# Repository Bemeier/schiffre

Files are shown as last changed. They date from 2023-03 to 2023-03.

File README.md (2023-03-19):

# SCHIFFRE

The Schiffre project is a mechanical keyboard featuring a host board and shield design, using a Flexible Flat Cable (FFC) as interconnect.
All PCBs designed with Kicad 7.0. Case designed in Fusion.

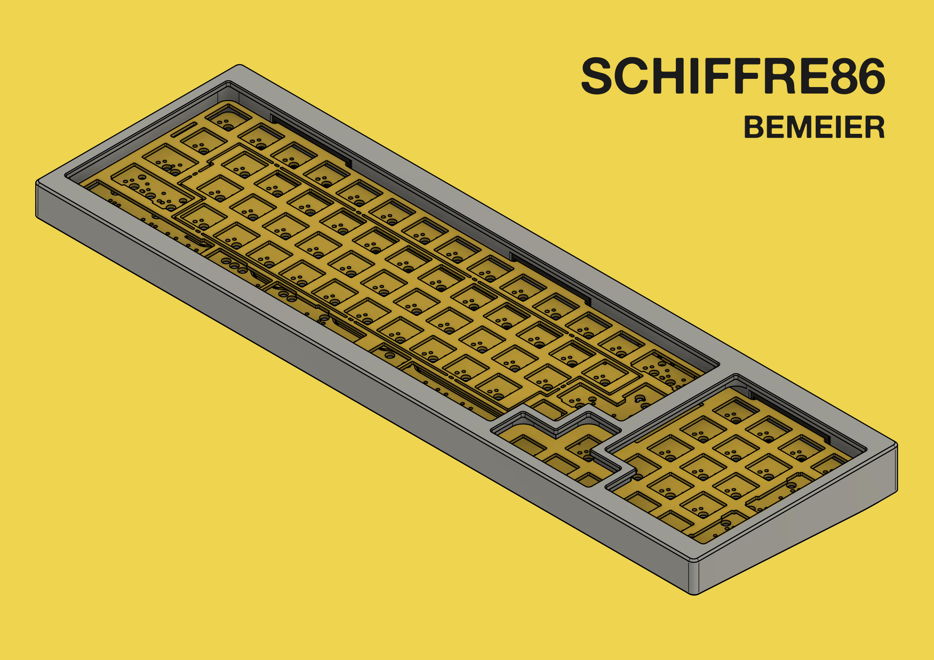
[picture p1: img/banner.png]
schiffre86 banner

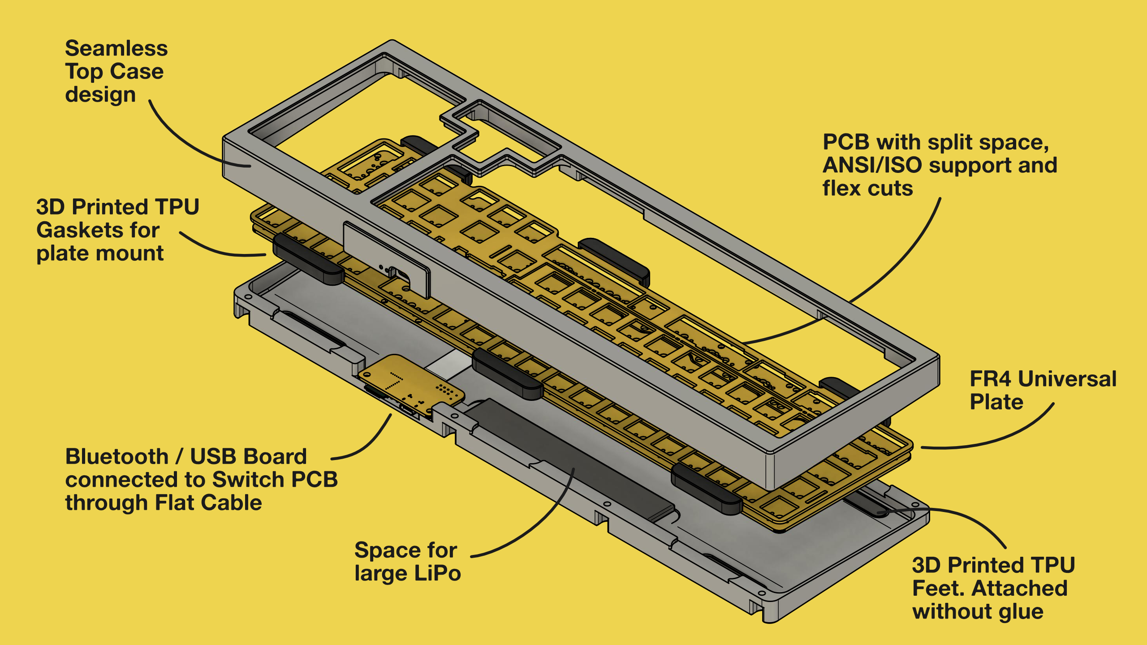
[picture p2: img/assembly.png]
schiffre86 assembly


## COMPONENTS
In this repository you will find everything to build a Schiffre 86 board.

- The host board: `schiffre_nrf`
- The shield PCB: `schiffre_86_pcb`
- The switch plate: `schiffre_86_plate`, with files for production from FR4.
- The case: `schiffre_86_case`, designed with both 3D printing and CNC machining in mind.

In addition there is a breakout board for the 30 pin FFC connector, with a RPi Pico header in `schiffre_pico`.

## BOM
See the production subfolders in the respective folders for the smd/assembly components.
Some additional components need to be ordered seperately.

**For the NRF host board (`schiffre_nrf`):**
 - One E73-2G4M08S1C bluetooth module [AliExpress](https://aliexpress.com/item/32944356249.html)
 - One 100mm reversible FFC calbe with 30 pins and .5mm pitch [AliExpress](https://aliexpress.com/item/1005002259855390.html) to connect between the host and shield pcb (`schiffre_86_pcb`).
 - A LiPo rechargable battery. There is room for a long, but narrow and thin one.
   - Thickness <= 4mm, and width <= 25mm. 
   - Make sure to only use LiPos with battery protection ICs included (usually the case).
   - 4x20x60mm 600mAh [AliExpress](https://aliexpress.com/item/1005005086965061.html)
   - 4x25x100mm 1200mAh [AliExpress](https://aliexpress.com/item/1005005067026996.html)

**For the Case (`schiffre_86_case`):**
 - M3x5.7x4.6 and M2x4x3.6 Heat-set inserts (if 3D printing the case or machining from plastics) [AliExpress](https://www.aliexpress.com/item/4001258499799.html).
 - DIN912 socket head screws: 8x M3x10mm, 4x M2x6mm [AliExpress](https://www.aliexpress.com/item/32810872544.html)
 - Plate mounting gaskets and case feet need to be 3D printed from TPU.

## FIRST BUILD
Below some pictures of the first build in progress.
PCBs from JLCPCB, case 3D printed from PETG.

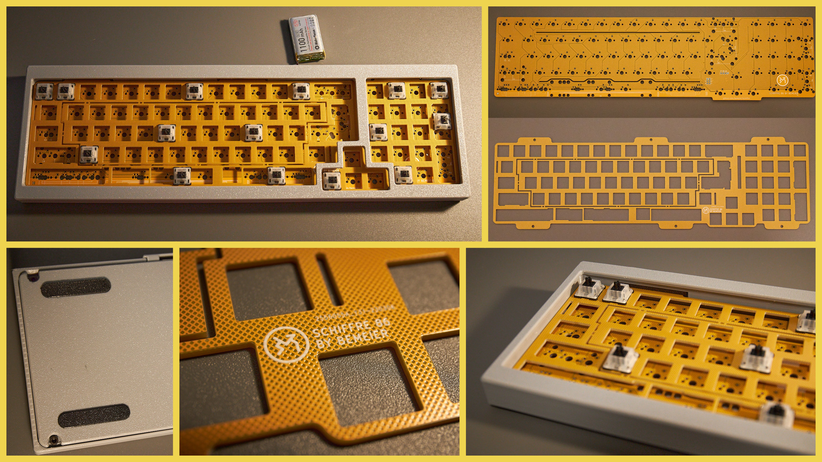
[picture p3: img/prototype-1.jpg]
pictures of prototype 1

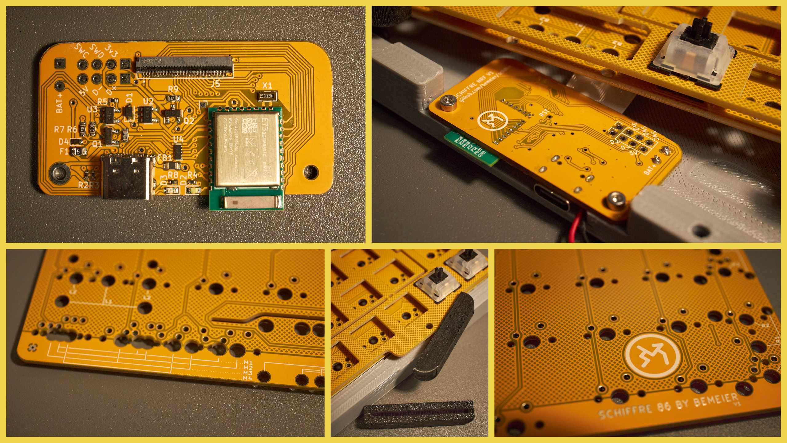
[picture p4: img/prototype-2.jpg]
pictures of prototype 2


## LAYOUTS
The schiffre86 supports both ANSI and ISO (Enter, split left shift) layouts, split backspace, and split spacebars.
See the [keyboard layout editor](http://www.keyboard-layout-editor.com/#/gists/19b67d0e8a5331e922c6eb11a3dd6522) for details.

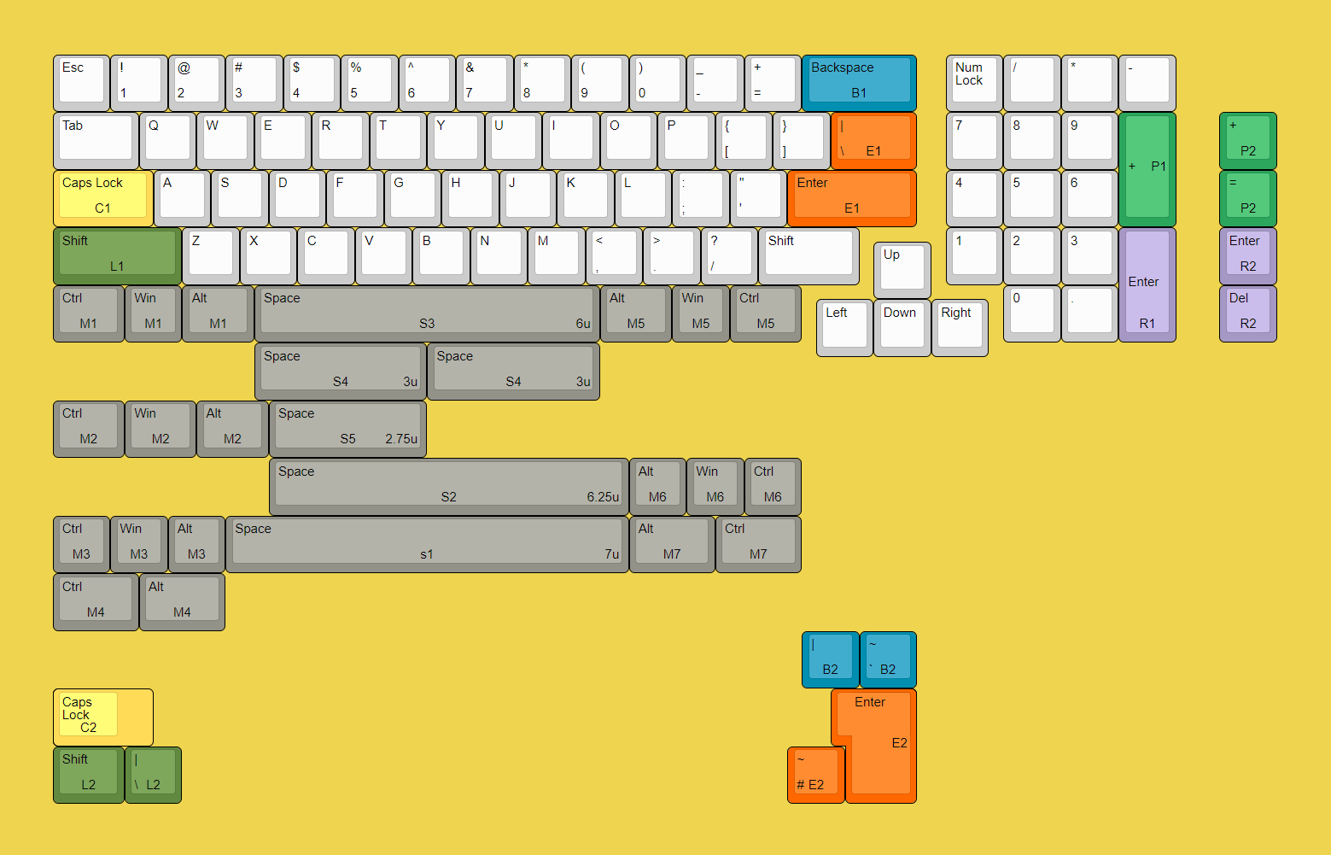
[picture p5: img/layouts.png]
schiffre86 supported layouts


## FIRMWARE
ZMK support works. See the [schiffre branch on our zmk fork](https://github.com/Bemeier/zmk/tree/schiffre). 
There is a [zmk-config template for the schiffre86](https://github.com/Bemeier/schiffre86-zmk-config) that you can clone to build your own keymap.
It comes with support for nickcoutsos' [keymap-editor](https://nickcoutsos.github.io/keymap-editor/).

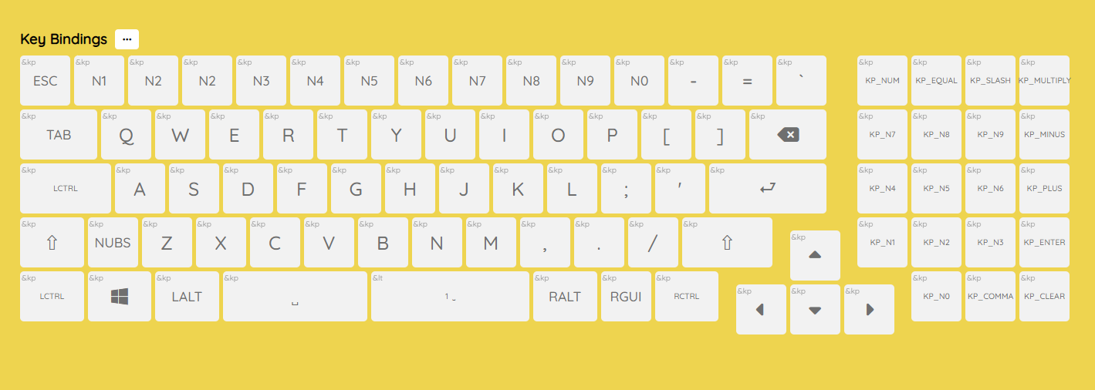
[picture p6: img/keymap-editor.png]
screenshot of keymap-editor showing the schiffre86


For a precompiled version see `schiffre86-schiffre_nrf-zmk.uf2` in the `firmware` folder.

For instructions on how to setup flashing the modules, refer to Joric's excellent [nrfmicro wiki](https://github.com/joric/nrfmicro/wiki/).
The main thing to do is to [flash the bootloader](https://github.com/joric/nrfmicro/wiki/Bootloader) onto the E73 modules.

## PROJECT NAME
*Schiffre* is a combination of the german word *Chiffre* (translation of Cypher, the board this project was based on originally), and the word *Schiff*, which means ship or big boat, reflecting the shape of the keyboard.

## TODO
 - Couldn't get the XTAL to work yet
 - Add some decoupling caps..
 - Add a Battery switch
 - Test the external power for backlight / LEDs.
 - Revisit the FCC pinout, especially with other aux devices that may be on the shield board (i.e. encoders or OLEDs)
 - Make FCC "reversible" i.e. mirror power pins.

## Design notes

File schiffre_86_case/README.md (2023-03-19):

# SCHIFFRE 86 CASE

A case for the Schiffre 86, housing the schiffre host board (schiffre_nrf), shield PCB (schiffre_86), and switch plate (schiffre_86_plate).

## 3D Printing
Top and Bottom case require a 400mm wide build area.  The main challenge when printing is the top case, which is more prone to warping due to it's geometry.
I've had better results with PETG (Overture PETG) than with PLA. I have yet to try ABS (a heated enclosure will be required).
Prototype was printed using a .6mm nozzle, .15mm layer height, 3 perimeters, 4-5 top/bottom layers, 50% cubic infill.

I've printed the gaskets and feet using Recreus Filaflex 82A TPU.

**NOTE: .STL's are NOT exported with the correct orientation**

## CNC
TODO

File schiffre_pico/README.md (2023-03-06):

# SCHIFFRE PICO

A Raspberry Pi Pico RP2040 compatible host board implementing the 30 pin Flexible Flat Cable interconnect.
This was mainly designed as a breakout board for the 30 pin connector.
This may be changed in the future to feature a form factor more suitable for integration in a case.

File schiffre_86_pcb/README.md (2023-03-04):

# SCHIFFRE 86 PCB
A (PCB for a) FRL Compact 1800-style board (i.e. Cypher) with 86 keys.
Desiged with flex cuts, and to be used floating, with a gasket mounted plate (see schiffre_86_plate).

Schiffre 86 is a *shield* PCB, without its own MCU.
See schiffre_nrf for a bluetooth powered host board, that can be attached using a Flexible Flat Cable (FFC) based interconnect.

## Layouts
There is an emphasis on providing several bottom row layout options, including a 2x3u split spacebar.
See the [KLE file](http://www.keyboard-layout-editor.com/#/gists/19b67d0e8a5331e922c6eb11a3dd6522) for more details on the supported options.

## Credits
Initial inspiration for the setup was based on [westfoxtrot's cypher_pcb](https://github.com/westfoxtrot/cypher_pcb) (although it's heavily modified since).

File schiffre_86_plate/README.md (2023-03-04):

# SCHIFFRE 86 PLATE

FR4 Universal 3/4 plate (allowing center alpha section of plate to be broken out for more flex).

This was created by exporting the plate outline sketch to DXF from Fusion, and importing it to KiCad as edge.cuts using the new import graphics function.

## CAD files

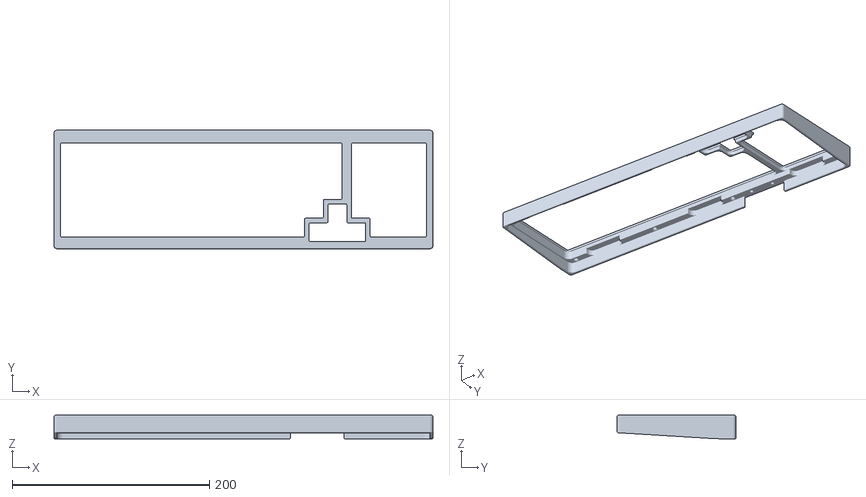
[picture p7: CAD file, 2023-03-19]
schiffre_86_case/stl/TopCase.stl
384.5 x 120.3 x 23.9

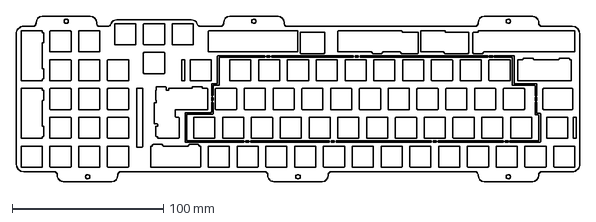
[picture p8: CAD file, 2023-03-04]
schiffre_86_plate/design/plate_profile.dxf
372.9 x 109.2 mm

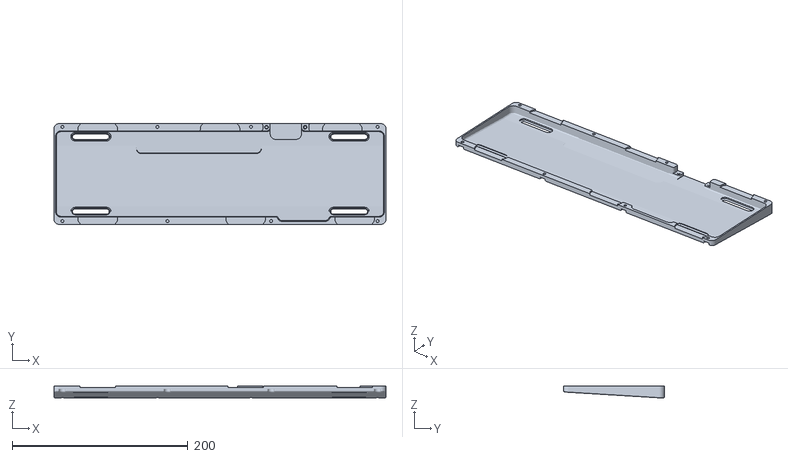
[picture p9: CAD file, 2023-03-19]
schiffre_86_case/stl/BottomCase.stl
378.0 x 114.8 x 14.0

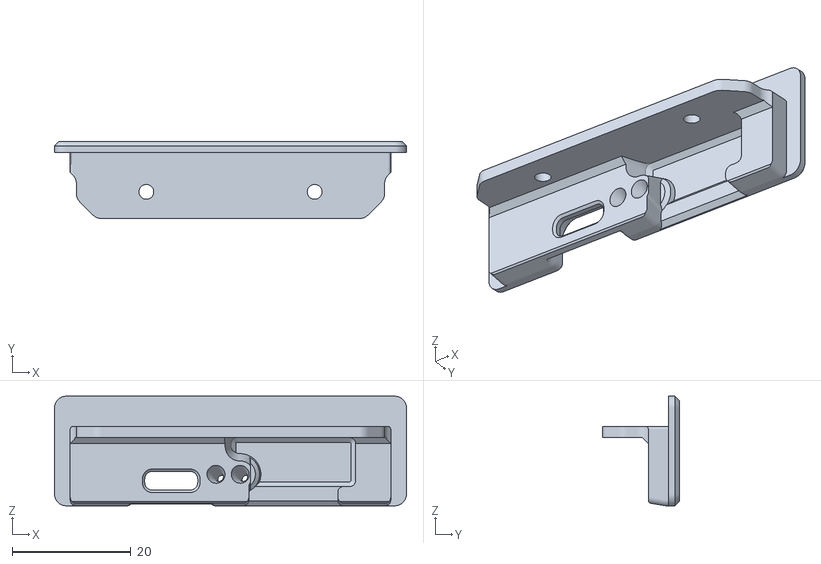
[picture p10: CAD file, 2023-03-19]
schiffre_86_case/stl/USBCover.stl
59.4 x 13.0 x 18.5

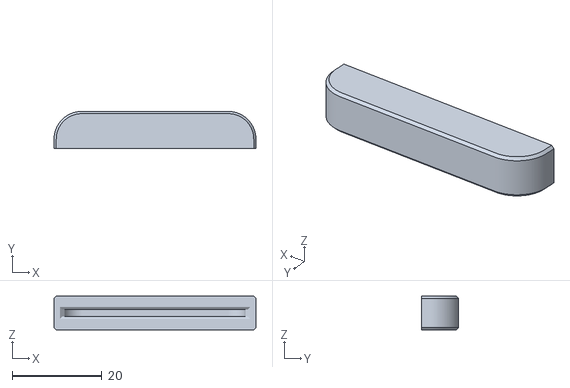
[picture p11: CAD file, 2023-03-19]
schiffre_86_case/stl/Gasket_6x.stl
45.0 x 8.30 x 7.55

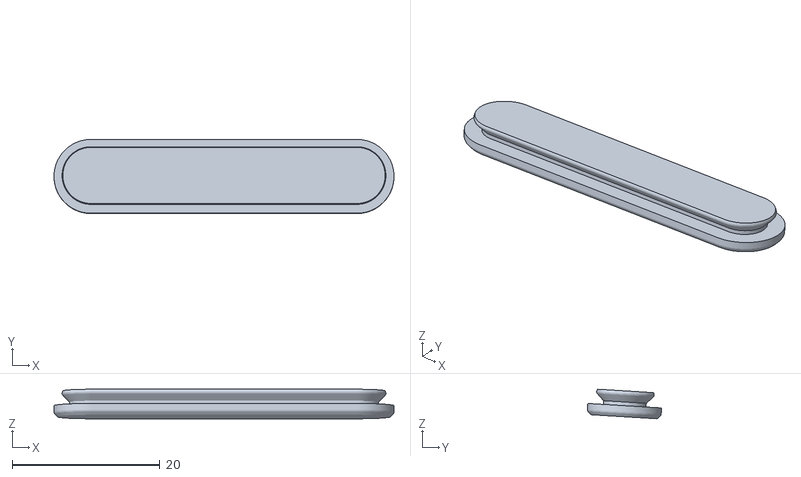
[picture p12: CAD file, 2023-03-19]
schiffre_86_case/stl/Feet_4x.stl
46.0 x 10.0 x 4.00

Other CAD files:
schiffre_86_case/source/schiffre86.f3d

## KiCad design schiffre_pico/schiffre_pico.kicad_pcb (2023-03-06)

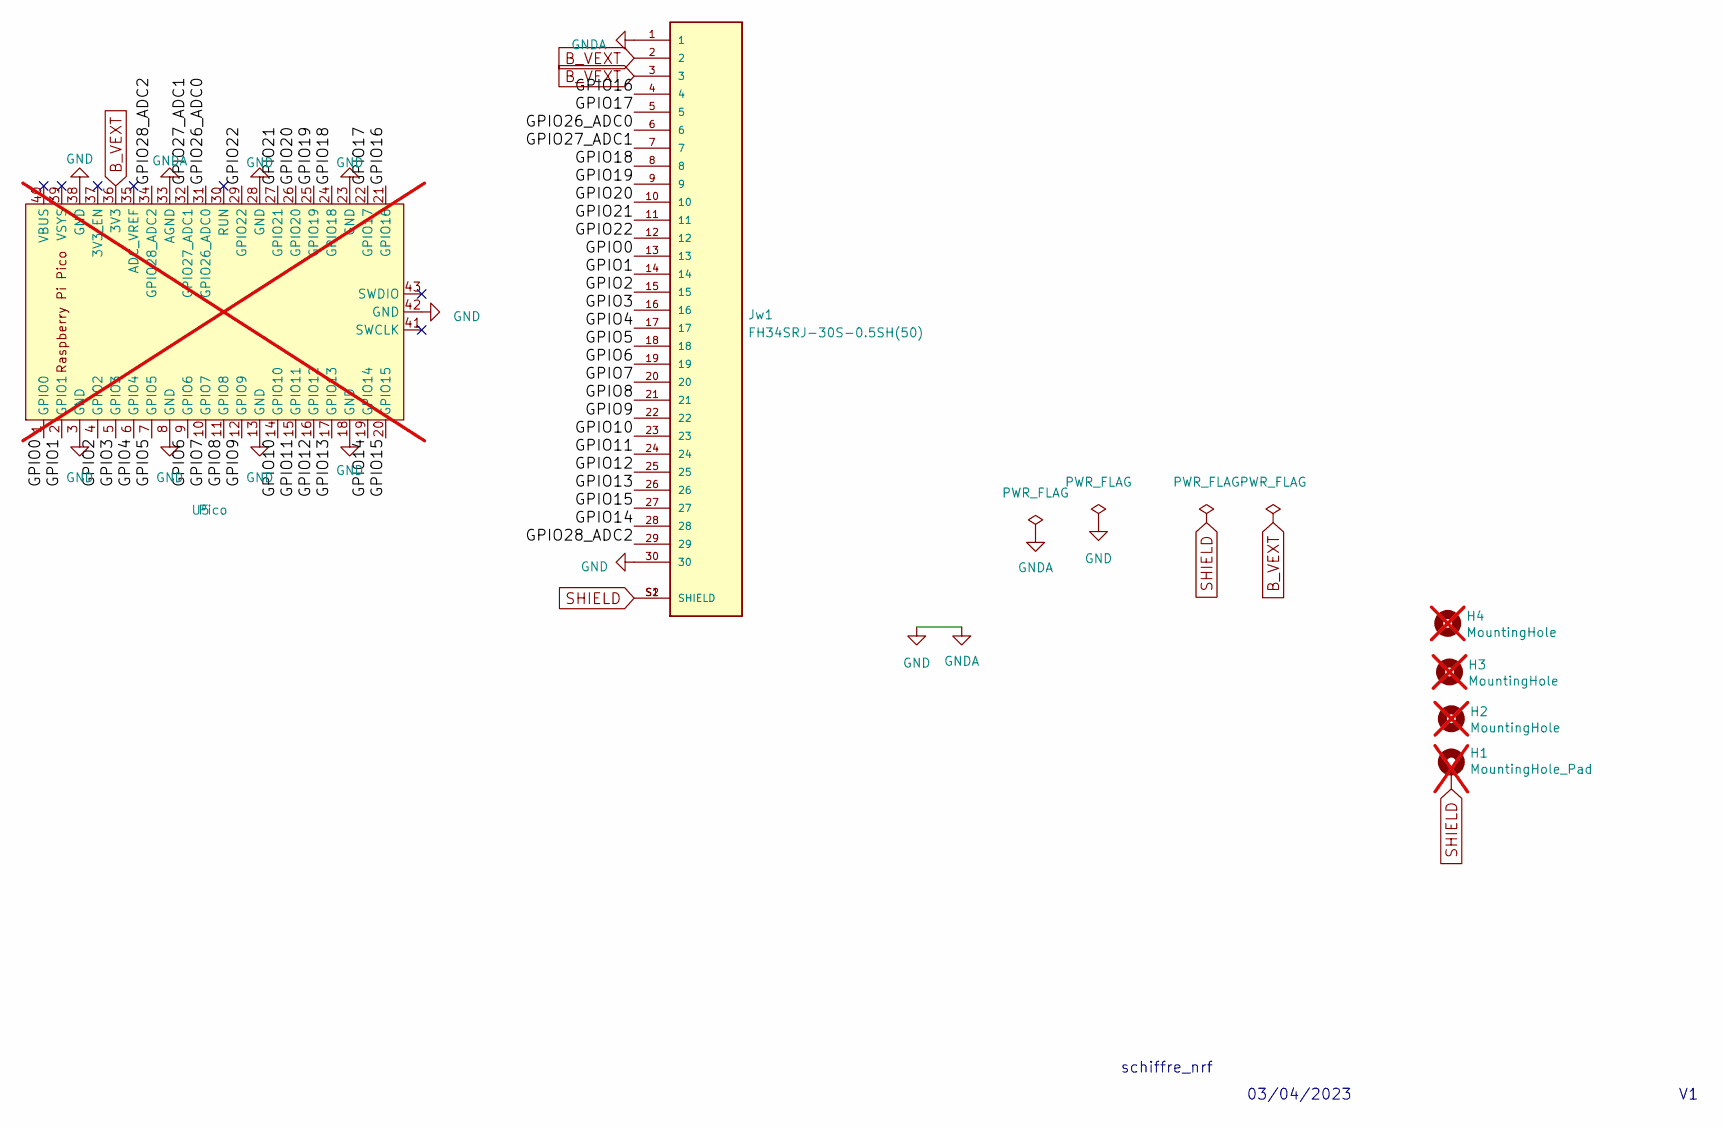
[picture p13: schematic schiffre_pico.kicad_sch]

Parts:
H1: MountingHole_Pad; MountingHole_2.2mm_M2_DIN965_Pad_TopBottom; not fitted
H2, H3, H4: MountingHole; MountingHole_2.2mm_M2_DIN965; not fitted
Jw1: FH34SRJ-30S-0.5SH(50); HRS_FH34SRJ-30S-0.5SH(50); PARTREV 1; JLCPART C324727
U5: Pico; RPi_Pico_SMD_TH; not fitted

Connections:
/GPIO0: Jw1.13, U5.1 (GPIO0)
/GPIO1: Jw1.14, U5.2 (GPIO1)
/GPIO2: Jw1.15, U5.4 (GPIO2)
/GPIO3: Jw1.16, U5.5 (GPIO3)
/GPIO4: Jw1.17, U5.6 (GPIO4)
/GPIO5: Jw1.18, U5.7 (GPIO5)
/GPIO6: Jw1.19, U5.9 (GPIO6)
/GPIO7: Jw1.20, U5.10 (GPIO7)
/GPIO8: Jw1.21, U5.11 (GPIO8)
/GPIO9: Jw1.22, U5.12 (GPIO9)
/GPIO10: Jw1.23, U5.14 (GPIO10)
/GPIO11: Jw1.24, U5.15 (GPIO11)
/GPIO12: Jw1.25, U5.16 (GPIO12)
/GPIO13: Jw1.26, U5.17 (GPIO13)
/GPIO14: Jw1.28, U5.19 (GPIO14)
/GPIO15: Jw1.27, U5.20 (GPIO15)
/GPIO16: Jw1.4, U5.21 (GPIO16)
/GPIO17: Jw1.5, U5.22 (GPIO17)
/GPIO18: Jw1.8, U5.24 (GPIO18)
/GPIO19: Jw1.9, U5.25 (GPIO19)
/GPIO20: Jw1.10, U5.26 (GPIO20)
/GPIO21: Jw1.11, U5.27 (GPIO21)
/GPIO22: Jw1.12, U5.29 (GPIO22)
/GPIO26_ADC0: Jw1.6, U5.31 (GPIO26_ADC0)
/GPIO27_ADC1: Jw1.7, U5.32 (GPIO27_ADC1)
/GPIO28_ADC2: Jw1.29, U5.34 (GPIO28_ADC2)
B_VEXT: Jw1.2, Jw1.3, U5.36 (3V3)
GND: Jw1.1, Jw1.30, U5.3 (GND), U5.8 (GND), U5.13 (GND), U5.18 (GND), U5.23 (GND), U5.28 (GND), U5.33 (AGND), U5.38 (GND), U5.42 (GND)
SHIELD: H1.1, Jw1.S1 (SHIELD), Jw1.S2 (SHIELD)

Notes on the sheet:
03/04/2023
schiffre_nrf

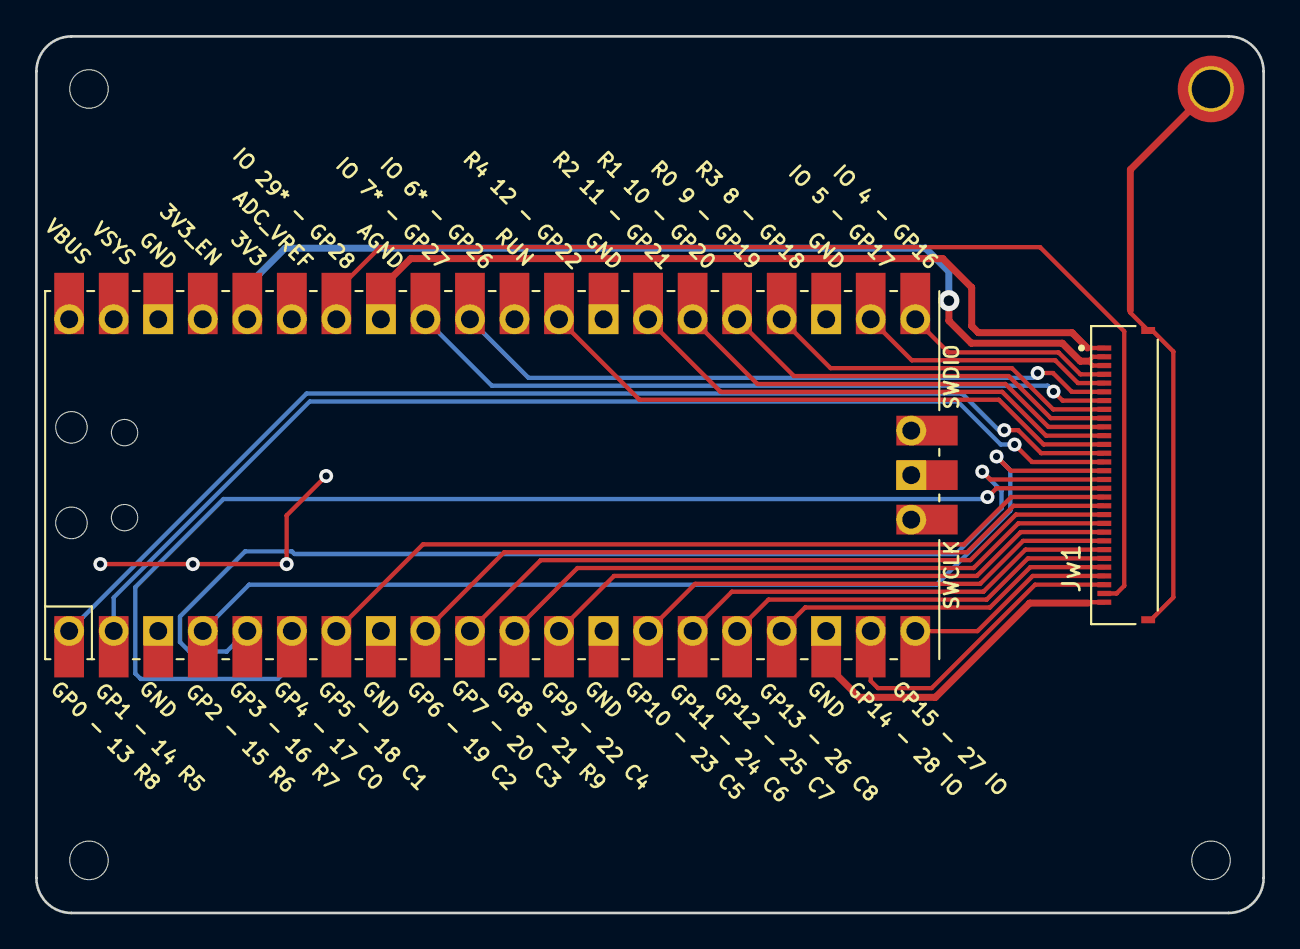
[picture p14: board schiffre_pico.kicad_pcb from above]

Board: 2 copper layers, 70.0 x 50.0 mm, 6 parts (0 on the bottom side), 29 nets.

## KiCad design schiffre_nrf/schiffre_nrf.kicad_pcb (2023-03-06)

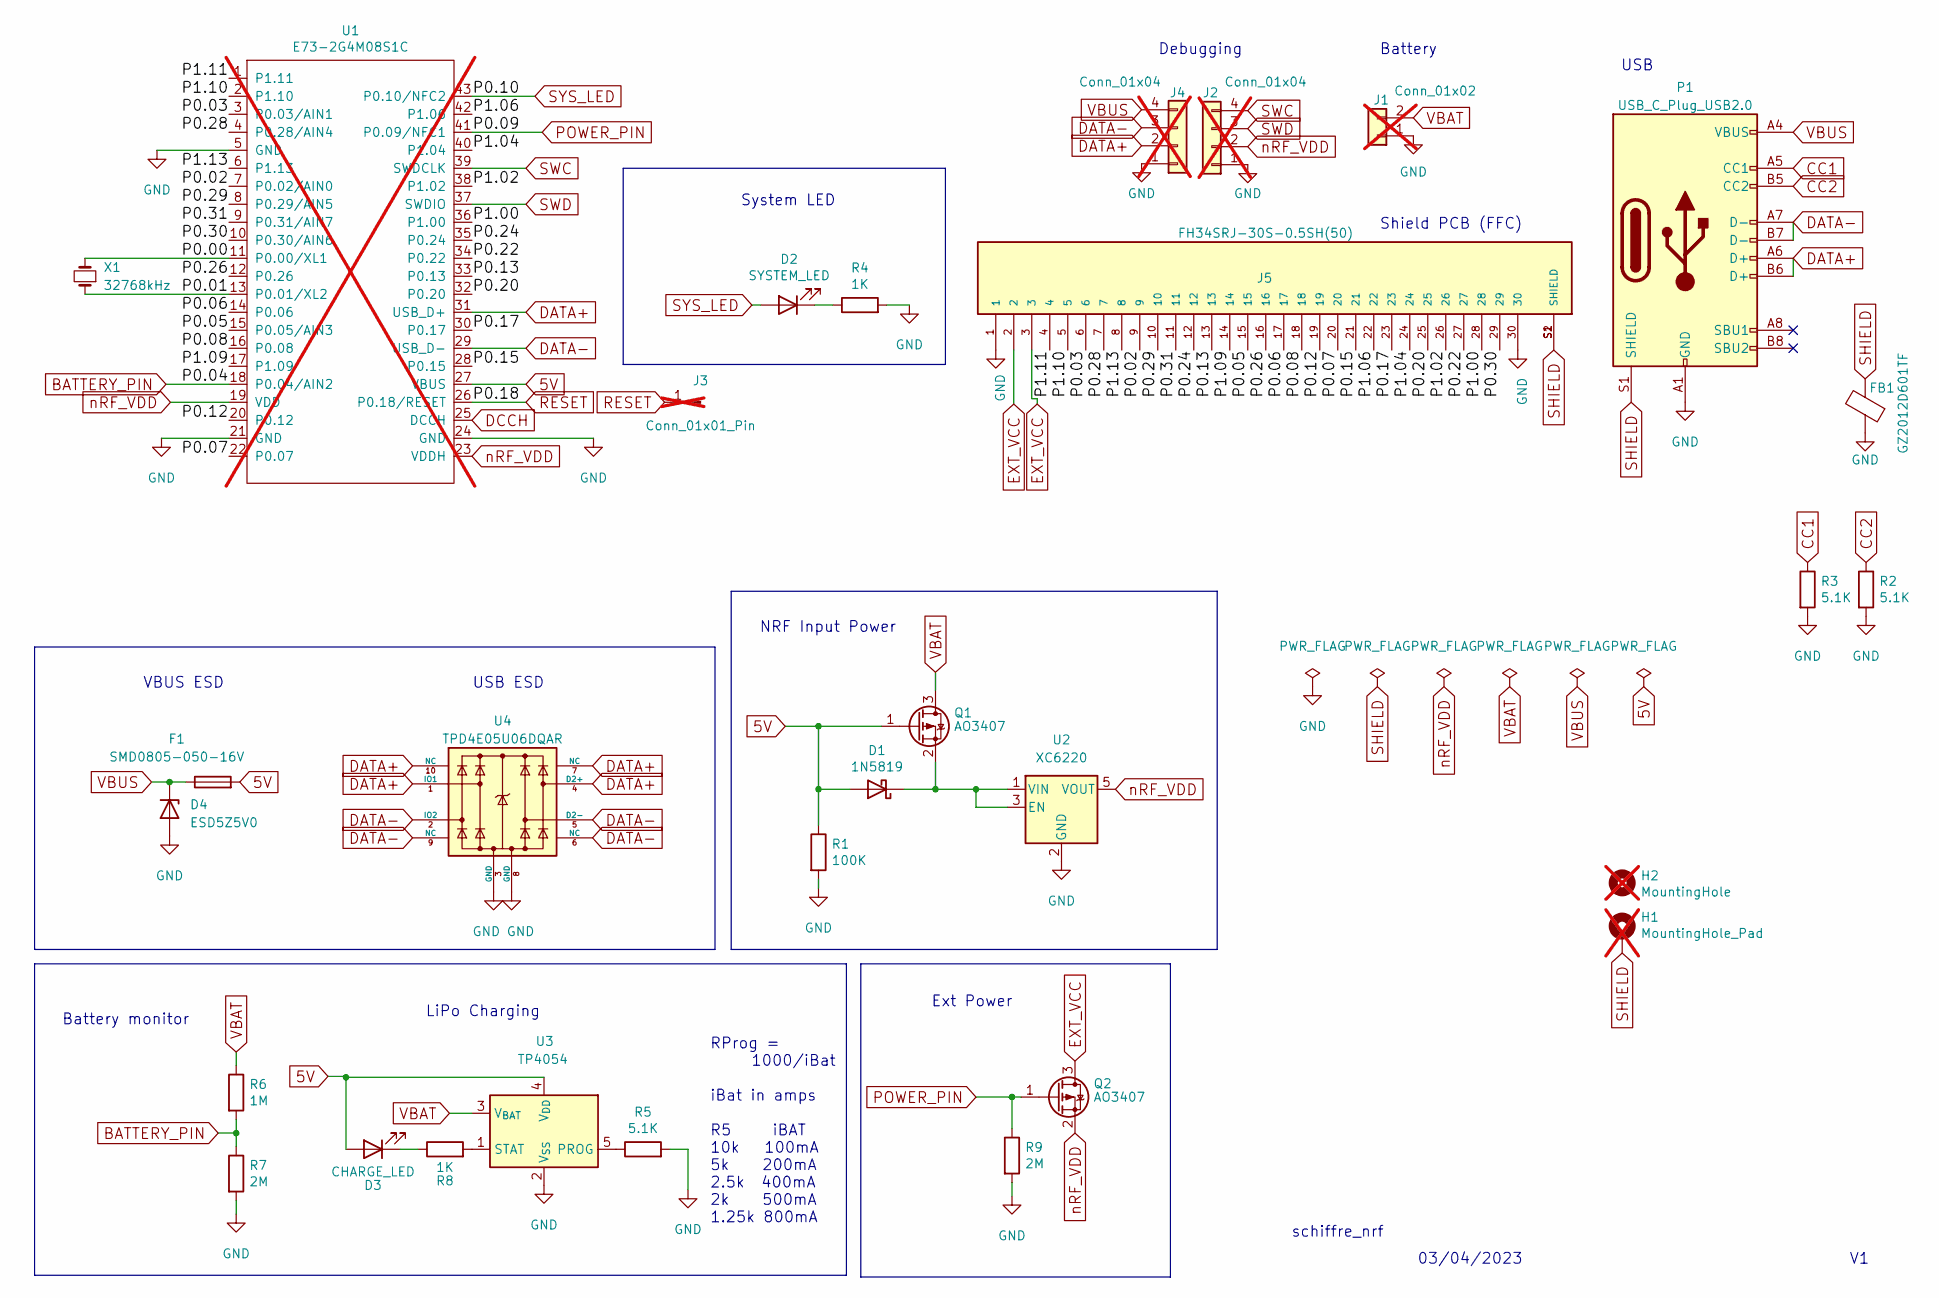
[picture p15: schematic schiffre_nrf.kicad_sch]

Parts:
D1: 1N5819; D_SOD-323F; MPN C191023
D2: SYSTEM_LED; LED_0603_1608Metric; MPN C2290
D3: CHARGE_LED; LED_0603_1608Metric; MPN C2286
D4: ESD5Z5V0; D_SOD-523; MPN C727161
F1: SMD0805-050-16V; Fuse_0805_2012Metric; MPN C2833485
FB1: GZ2012D601TF; L_0805_2012Metric; MPN C1017
H1: MountingHole_Pad; MountingHole_2.2mm_M2_DIN965_Pad_TopBottom; not fitted
H2: MountingHole; MountingHole_2.2mm_M2_DIN965; not fitted
J1: Conn_01x02; SolderWire-0.15sqmm_1x02_P4mm_D0.5mm_OD1.5mm; not fitted
J2, J4: Conn_01x04; PinSocket_1x04_P2.54mm_Vertical; not fitted
J3: Conn_01x01_Pin; PinHeader_1x01_P1.00mm_Vertical; not fitted
J5: FH34SRJ-30S-0.5SH(50); HRS_FH34SRJ-30S-0.5SH(50); PARTREV 1; JLCPART C324727
P1: USB_C_Plug_USB2.0; USB_C_Receptacle_Palconn_UTC16-G_3D; MPN C709357; JLCPART C709357
Q1, Q2: AO3407; SOT-23; MPN C351408
R1: 100K; R_0603_1608Metric; MPN C25803
R2, R3, R5: 5.1K; R_0402_1005Metric; MPN C25905
R4, R8: 1K; R_0402_1005Metric; MPN C11702
R6: 1M; R_0603_1608Metric; MPN C22935
R7, R9: 2M; R_0603_1608Metric; MPN C22976
U1: E73-2G4M08S1C; E73-2G4M08S1C-52840; not fitted
U2: XC6220; SOT-23-5; MPN C86534
U3: TP4054; SOT-23-5; MPN C32574
U4: TPD4E05U06DQAR; USON-10_2.5x1.0mm_P0.5mm; Manufacturer Part # TPD4E05U06DQAR; LCSC Part # C138714
X1: 32768kHz; Crystal_SMD_3215-2Pin_3.2x1.5mm; MPN C32346

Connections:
5V: D1.2 (A), D3.2 (A), F1.2, Q1.1 (G), R1.1, U1.27 (VBUS), U3.4 (V_{DD})
/P0.00: U1.11 (P0.00/XL1), X1.2
/P0.01: U1.13 (P0.01/XL2), X1.1
/P0.02: J5.9, U1.7 (P0.02/AIN0)
/P0.03: J5.6, U1.3 (P0.03/AIN1)
/P0.05: J5.15, U1.15 (P0.05/AIN3)
/P0.06: J5.17, U1.14 (P0.06)
/P0.07: J5.20, U1.22 (P0.07)
/P0.08: J5.18, U1.16 (P0.08)
/P0.12: J5.19, U1.20 (P0.12)
/P0.13: J5.13, U1.33 (P0.13)
/P0.15: J5.21, U1.28 (P0.15)
/P0.17: J5.23, U1.30 (P0.17)
/P0.20: J5.25, U1.32 (P0.20)
/P0.22: J5.27, U1.34 (P0.22)
/P0.24: J5.12, U1.35 (P0.24)
/P0.26: J5.16, U1.12 (P0.26)
/P0.28: J5.7, U1.4 (P0.28/AIN4)
/P0.29: J5.10, U1.8 (P0.29/AIN5)
/P0.30: J5.29, U1.10 (P0.30/AIN6)
/P0.31: J5.11, U1.9 (P0.31/AIN7)
/P1.00: J5.28, U1.36 (P1.00)
/P1.02: J5.26, U1.38 (P1.02)
/P1.04: J5.24, U1.40 (P1.04)
/P1.06: J5.22, U1.42 (P1.06)
/P1.09: J5.14, U1.17 (P1.09)
/P1.10: J5.5, U1.2 (P1.10)
/P1.11: J5.4, U1.1 (P1.11)
/P1.13: J5.8, U1.6 (P1.13)
BATTERY_PIN: R6.2, R7.1, U1.18 (P0.04/AIN2)
CC1: P1.A5 (CC1), R3.1
CC2: P1.B5 (CC2), R2.1
DATA+: J4.2, P1.A6 (D+), P1.B6 (D+), U1.31 (USB_D+), U4.1 (IO1), U4.4 (D2+), U4.7 (NC), U4.10 (NC)
DATA-: J4.3, P1.A7 (D-), P1.B7 (D-), U1.29 (USB_D-), U4.2 (IO2), U4.5 (D2-), U4.6 (NC), U4.9 (NC)
DCCH: U1.25 (DCCH)
EXT_VCC: J5.2, J5.3, Q2.3 (D)
GND: D4.2 (A), FB1.1, J1.1, J2.1, J4.1, J5.1, J5.30, P1.A1 (GND), P1.A12 (GND), P1.B1 (GND), P1.B12 (GND), R1.2, R2.2, R3.2, R4.2, R5.2, R7.2, R9.2, U1.5 (GND), U1.21 (GND), U1.24 (GND), U2.2 (GND), U3.2 (V_{SS}), U4.3 (GND), U4.8 (GND)
unnamed: D1.1 (K), Q1.2 (S), U2.1 (VIN), U2.3 (EN)
unnamed: D2.1 (K), R4.1
unnamed: D3.1 (K), R8.1
unnamed: R5.1, U3.5 (PROG)
unnamed: R8.2, U3.1 (STAT)
POWER_PIN: Q2.1 (G), R9.1, U1.41 (P0.09/NFC1)
RESET: J3.1, U1.26 (P0.18/RESET)
SHIELD: FB1.2, H1.1, J5.S1 (SHIELD), J5.S2 (SHIELD), P1.S1 (SHIELD)
SWC: J2.4, U1.39 (SWDCLK)
SWD: J2.3, U1.37 (SWDIO)
SYS_LED: D2.2 (A), U1.43 (P0.10/NFC2)
VBAT: J1.2, Q1.3 (D), R6.1, U3.3 (V_{BAT})
VBUS: D4.1 (K), F1.1, J4.4, P1.A4 (VBUS), P1.A9 (VBUS), P1.B4 (VBUS), P1.B9 (VBUS)
nRF_VDD: J2.2, Q2.2 (S), U1.19 (VDD), U1.23 (VDDH), U2.5 (VOUT)

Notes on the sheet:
LiPo Charging
03/04/2023
VBUS ESD
RProg = 1000/iBat iBat in amps R5 iBAT 10k 100mA 5k 200mA 2.5k 400mA 2k 500mA 1.25k 800mA
Debugging
USB
NRF Input Power
schiffre_nrf
USB ESD
System LED
Shield PCB (FFC)
Battery monitor
Battery
Ext Power

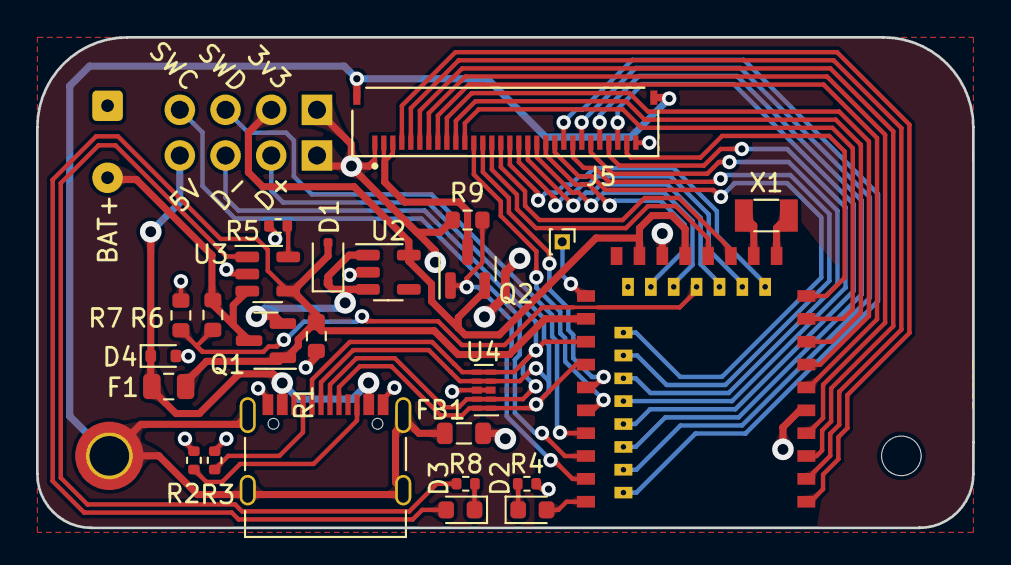
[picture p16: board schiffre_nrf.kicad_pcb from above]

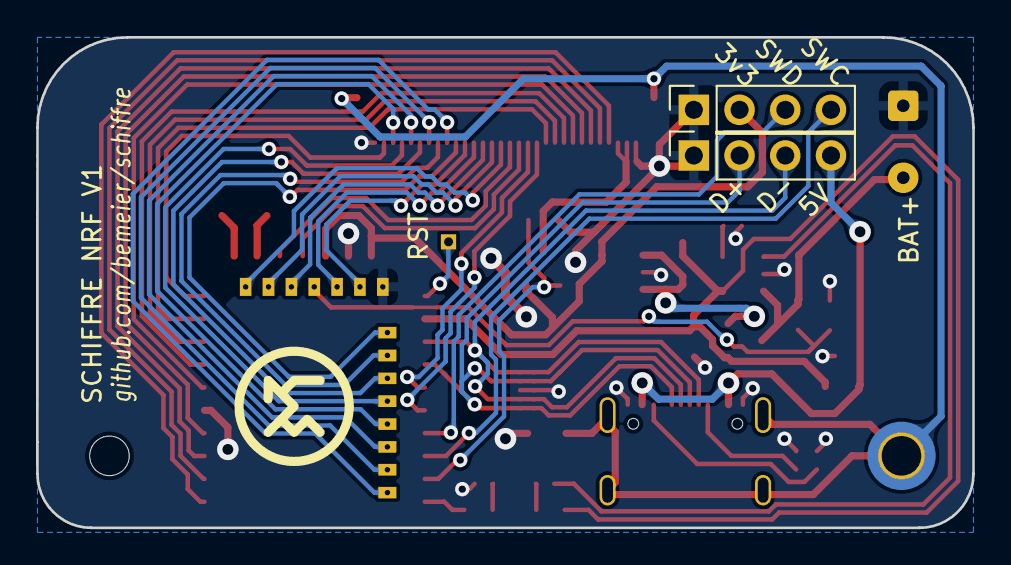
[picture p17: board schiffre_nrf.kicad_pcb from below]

Board: 2 copper layers, 52.0 x 27.2 mm, 30 parts (3 on the bottom side), 50 nets.

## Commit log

2023-03-04 Initial commit. First version of PCBs that went into production.
    [pico_breakout.kicad_sch, plate_profile.dxf, schiffre_86_matrix.kicad_sch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]
2023-03-06 factored out the pico breakout board
    [pico_breakout.kicad_sch, schiffre_nrf.kicad_pcb, schiffre_nrf.kicad_sch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]
2023-03-06 small drc things
    [schiffre_nrf.kicad_sch, schiffre_pico.kicad_pcb, schiffre_pico.kicad_sch]
2023-03-19 added case files
    [BottomCase.stl, Feet_4x.stl, Gasket_6x.stl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]
2023-03-19 readme case
2023-03-19 pictures of first prototype
